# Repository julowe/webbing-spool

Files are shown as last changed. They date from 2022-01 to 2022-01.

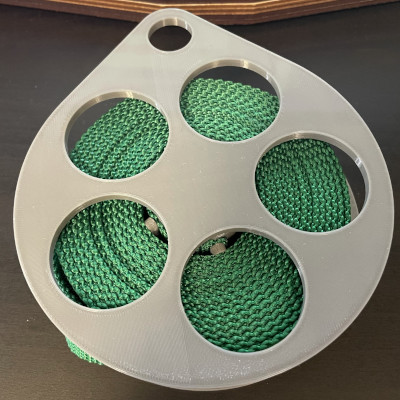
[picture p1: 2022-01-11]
spool-assembled-small.jpeg

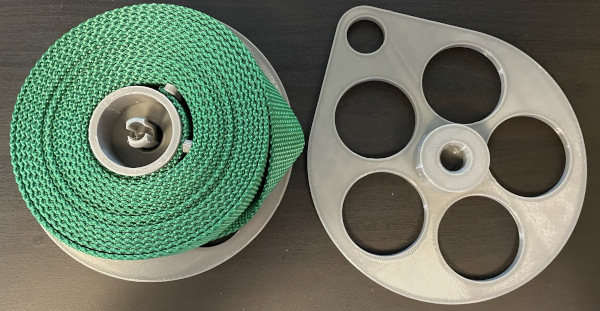
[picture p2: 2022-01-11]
spool-disassembled-small.jpeg

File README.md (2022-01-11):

# Webbing Spool
3d model of a parametric spool for webbing - availabe at https://www.thingiverse.com/thing:4630397

## Inspiration
I really liked the [climbing webbing spool](https://www.thingiverse.com/thing:2325788) made by [DtEW](https://www.thingiverse.com/dtew/designs) but wanted some changes. Namely - the ability to easily spool off webbing, but their version required the webbing to go through both hubs or gluing the hubs together. So this one desired change led down the rabbit hole to many iterations and other ideas.

## Changes
This model was made from scratch by me in OpenSCAD - even though the base object looks pretty much the same externally.

The spool wheels are still printed individually, but now have a central annular snap-fit joint & pin to hold them together and allow for rotation. Webbing retaining clips were added one wrap/webbing thickness away from central hub.

The model is mostly (all?) parametric, but with little to no in-code error checking. Any number of spool wheel holes can be created, and any width and length webbing can be accommodated. The customizer code has some limitations, but easy enough to change or override those in the code itself. Default facets for creating cylinders is low, so that the object previews quickly. Change it higher in final render, or central hubs proably won't spin around each other smoothly (or at all?).

Future version will hopefully have a MOLLE/generic clip attachment option as well.

## Files
Included in repo are the scad file and STL files for 1 inch wide webbing at 15 foot length.

The included STL files have been printed and do work. They are also the same as available on [Thingiverse](https://www.thingiverse.com/thing:4630397)

* webbingSpool.scad - parametric OpenSCAD file. Most variables should be commented and well explained...
* webbingSpool-bottom.stl - bottom wheel has retaining clips around the central hub which you feed webbing past so it stays in places as you wind up webbing (probably not strictly neccessary). After assembly, this spool rotates as you pull webbing. Print with large wheel on build plate, hub and retaining clips pointing positive Z.
* webbingSpool-top.stl - top wheel that does not rotate. Currently has carabiner clip hole, future TODO will be MOLLE attachment method or at least a generic belt type clip. Print with large wheel on build plate, hub pointing positive Z.
* webbingSpool-peg.stl - central annular (cantilevered?) snap-fit peg. Print with long central axis parallel to build plate. This makes the deformation force (when inserting peg into holes) perpendicular to layer lines.

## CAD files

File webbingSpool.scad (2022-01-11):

// webbing spool
//justin lowe 2021-01-11

/* TODO

- fix up comments to support customizer style (line before, not trailing)
- check overlap of circles to remove from spool wheel, increase number for longer webbing lengths (over ~20ft). Or make ovals?
- ugh, add some padding to all differences just so that previews of objects will not have artifcating?
- tweak some built in dimensions - inner hub diam, wheel thickness, hub wall thickness
- clip to snap on to wheel for another attachemtn option (other than/in addition to carabiner hole)

*/
//


/* [Output Options] */

//Cylinder Facets - IMPORTANT: Choose higher (>= 90) for smooth final render/object, smaller for quick draft preview. (Default is set small so Thingiverse will create preview quicker)
Current_Facets = 18; // [18,36,90,180]
//FYI: 18 is what I usually use for previews, 90 or 180 for final renders.
$fn = Current_Facets;

//Make Bottom of Spool Wheel, Top of Spool Wheel, or central joining Peg
Output_Object = "Peg"; // [Bottom, Top, Peg]


/* [Webbing Info] */

//Width of Webbing (in mm)
Webbing_Width = 25.25; 
//actual 25.25mm

//Length of Webbing (in feet) (Longer than 20' currently generates unprintable objects, need to fix that...)
Webbing_Length_ft = 15; // [2:0.5:21]
// [2:0.5:100]
webbingLength = 305 * Webbing_Length_ft; //305mm in one ft

//Thickness of Webbing (in mm)
Webbing_Thickness = 2;

//Space (in mm) to add between Webbing Retaining Clips aroudn central hub and Webbing itself. Changing this will make webbing easier or harder to thread/pull past clip
Webbing_Thickness_Padding_For_Clips = 0.1;
//webbingLength = 305 * .00001; //305mm in one ft

/* [Carabiner Info] */
//most carabiners seem to be 10 to 14mm diameter materials

//Diameter (in mm) of hole for carabiner/attachment point
Carabiner_Hole_Diameter = 18; 
//18mm = 0.7inches

//Distance (in mm) from edge of material to edge of hole for carabiner
Carabiner_Hole_Edge_Threshold_Distance = 5;

/* [Retainer Clips] */
//Number of clips that will hold webbing against central hub of Spool
Webbing_Clip_Number = 2;

module __Just_A_Module_to_stop_below_values_from_showing_in_Customizer__ () {}
//https://en.m.wikibooks.org/wiki/OpenSCAD_User_Manual/Customizer#supported_variables

//still retainer clip info, but probably shouldn't be easily chagned by user/in customizer
webbingClipWidth = 5;
webbingClipDepth = 3;


//spool info
//TODO Change this padding?? Prob don't need quite as much
hubInnerInnerDiameter = 24; //empty space in center of spool, bottom wheel
hubInnerInnerRadius = hubInnerInnerDiameter/2;
//TODO make wall thinner? test print
hubWallThickness = 3;
hubInnerOuterGap = 0.3; //gap for smooth spinning

hubInnerOuterDiameter = hubInnerInnerDiameter + (hubWallThickness * 2) - (hubInnerOuterGap * 2); //bottom wheel, two wheels of walls plus gap on each side

hubOuterInnerDiameter = hubInnerInnerDiameter + (hubWallThickness * 2); //top wheel, two wheels of walls 
hubOuterOuterDiameter = hubOuterInnerDiameter + (hubWallThickness * 2); //top wheel, wall thickness on both sides

//diameter to radius
hubInnerOuterRadius = hubInnerOuterDiameter/2;
hubOuterOuterRadius = hubOuterOuterDiameter/2;
hubOuterInnerRadius = hubOuterInnerDiameter/2;

spoolGapWidth = Webbing_Width + 3; //total gap between two wheels of spool and wide edge of webbing
spoolOuterRadiusPadding = 5; //how much overhang of spool wheels past spooled webbing

//TODO make thinner? 3? 2?
wheelHeight = 4;
wheelSubtractionHoleOuterPadding = 7; //distance between subtracted hole and outer edge of wheel
wheelSubtractionHoleNumber = 5; //7 holes will overlap each other
//could find cirumference of circle at translation point and verify that total diameter of holes does not exceed that, plus fudge since straight line vs circle... worth it?? prob not



//snapfit info
snapFitJointVerticalGap = 0.5; //how much void vertically on bottom and top between peg and spool wheel hub receiver
snapFitPegJoinHeight = 2; //how much soild space at middle vertical of peg shaft
snapFitJointHeight = 5; //how tall is the torus
snapFitPegJointShaftOverlapRadius = snapFitJointHeight/4; //how much overlap between shaft cylinder and torus (not part of overall shaft height calculation) //so 10.5mm diameter shaft
snapFitPegVerticalOverlap = snapFitJointHeight*2/3;
snapFitJointVoidDiameter = 8; //horizontal diameter of void in peg snap fit joint
snapFitJointHorizontalGap = 0.5; //not used for peg, but for voids in spool hubs
snapFitPegJointSeperation = spoolGapWidth - (2*snapFitJointVerticalGap) - (2*snapFitJointHeight); //how tall is shaft connecting two toruses
echo("snap Fit Peg Joint Seperation = ", snapFitPegJointSeperation);
snapFitPegHorizontalGap = 0.5;

//how much of peg radius to chop off the two sides
snapFitSquaring = 0.1*snapFitJointHeight/2;





//snapFitSphereJointWallThickness = 2;
//snapFitSphereJointWallInsideGap = 1; //between ball joint and snap fit receiver
//snapFitSphereJointWallOutsideGap = 1; //between snap fit receiver and outer cylinder, to allow for some flex inside spool central cylinder XX

//FYI
//Webbing_Width = 25.25; //actual 25.25
//hubInnerInnerDiameter = 24; //this could be changed. arbitrary

//snapFitJointVerticalGap = 1;
//snapFitPegJointSeperation = 8; //distance on peg between two toruses
//snapFitPegJoinHeight = 4;
//snapFitJointHeight = (Webbing_Width - snapFitPegJointSeperation - (2*snapFitJointVerticalGap))/2;
//echo("Snap Fit JointHeight = ", snapFitJointHeight);
//snapFitJointHeight



//snapFitSpherePeg = hubInnerInnerDiameter - (2*hubWallThickness) - (2*snapFitSphereJointWallThickness) - (2*snapFitSphereJointWallInsideGap) - (2*snapFitSphereJointWallOutsideGap);
//snapFitSphereJointInsideDiameter = snapFitSpherePeg + (2*snapFitSphereJointWallInsideGap);
//snapFitSphereJointOutsideDiameter = snapFitSpherePeg + (2*snapFitSphereJointWallInsideGap) + (2*snapFitSphereJointWallThickness);
//echo("Snap Fit Sphere Peg Diameter = ", snapFitSpherePeg);
//echo("Snap Fit Sphere Joint Outer Diameter = ", snapFitSphereJointOutsideDiameter);

//TODO remove all falnge code
//flange info
//flangeInsetWidthRadiusX = 2;
//flangeInsetRadiusZ = 2;
//flangeBumpWidthRadiusX = 1.3;
//flangeBumpRadiusZ = 2;
//clipPerfX = hubWallThickness+4;
//clipPerfY = 3;
//clipPerfZFactor = 4;
//clipPerfSolidY = 3;
//clipPerfHubFactor = 0.7;
//hubInnerInnerCircumference = hubInnerInnerDiameter * PI;
//clipPerfNumberCalc = hubInnerInnerCircumference / (clipPerfY + clipPerfSolidY);
//echo("Clip perf calculated number  = ", clipPerfNumberCalc);
//clipPerfNumber = floor(clipPerfNumberCalc);
//echo("Clip perf number  = ", clipPerfNumber);
//clipPerfRotation = 360/clipPerfNumber;

//calculated spool info
WebbingNumberTurns = (Webbing_Thickness - hubOuterOuterDiameter + sqrt(pow(hubOuterOuterDiameter - Webbing_Thickness,2)+((4 * Webbing_Thickness * webbingLength)/PI)))/(2 * Webbing_Thickness);
webbingSpooledDiameter = (2 * WebbingNumberTurns * Webbing_Thickness) + hubOuterOuterDiameter;
SpoolOuterDiameter = webbingSpooledDiameter + (2 * spoolOuterRadiusPadding);
echo("Spool diameter = ", SpoolOuterDiameter);

spoolWorkingRadius = (SpoolOuterDiameter/2) - (hubInnerInnerRadius + 2 * hubWallThickness);
wheelSubtractionHoleDiameter = spoolWorkingRadius - wheelSubtractionHoleOuterPadding;
wheelSubtractionHoleRadius = wheelSubtractionHoleDiameter/2;
wheelSubtractionHoleTranslation = wheelSubtractionHoleRadius + (hubInnerInnerRadius + 2 * hubWallThickness);
wheelSubtractionHoleRotation = 360/wheelSubtractionHoleNumber;

//clip hole info
clipSquareDiagonal = abs(sqrt(pow((SpoolOuterDiameter/2),2) * 2));
clipRoundingHoleDiameter = clipSquareDiagonal - SpoolOuterDiameter/2;
//clipHoleCenterTranslation = SpoolOuterDiameter/2 + (clipRoundingHoleDiameter/2);
clipRoundingHoleCenterTranslation = SpoolOuterDiameter/2 - (clipRoundingHoleDiameter/2);


echo("Clip square diagonal  = ", clipSquareDiagonal);
echo("Clip hole diameter = ", clipRoundingHoleDiameter);
echo("Clip Rounding cylinder translation = ", clipRoundingHoleCenterTranslation);
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

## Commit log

2020-10-21 first spool version
    Adding first version of spool and updating readme
    [webbingSpool.scad]
2020-10-21 Updated webbingSpool and readme. Added STLs
    switched to snapfit joint and sort of modularized pieces. STLs for 1", 15' webbing.
    [webbingSpool.scad]
2020-12-01 draft of clip for molle
    [webbingSpool.scad]
2022-01-10 split up modules to make individual stl generation easier
    [webbingSpool.scad]
2022-01-11 STLs: new stl files with naming convention change
2022-01-11 scad: rename and/or redefine some variables for customizer usage
    [webbingSpool.scad]
2022-01-11 images of printed object
